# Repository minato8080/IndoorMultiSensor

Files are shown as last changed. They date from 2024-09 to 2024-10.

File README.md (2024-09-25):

## 概要
温度、湿度、気圧、二酸化炭素濃度、時間を毎秒k更新して表示する室内用汎用モニタです。
秋月電子の16×2行のLCDモジュールが安かったのでデュアルディスプレイにしました。

BME280・MHZ19Cモジュールのライブラリについてはこちらお借りしました。
https://github.com/shapoco/pico-env-mon

## 電子部品
|項目|型番|購入先|
|:--|:--|:--|
|マイコン|Raspberry Pi Pico|https://akizukidenshi.com/catalog/g/g116132/|
|LCD|ACM1602K-NLW-BBW *2|https://akizukidenshi.com/catalog/g/g110185/|
|温湿度・気圧センサ|AE-BME280|https://akizukidenshi.com/catalog/g/g109421/|
|CO2 センサ|MH-Z19C|https://akizukidenshi.com/catalog/g/g116142/|
|タクトスイッチ||https://akizukidenshi.com/catalog/g/g103647/|
|RTC|AE-RX8900|https://akizukidenshi.com/catalog/g/g113009/|
|電気二重層コンデンサー|1.5F5.5V|https://akizukidenshi.com/catalog/g/g104300/|
|整流用ダイオード|1000V1A|https://akizukidenshi.com/catalog/g/g100934/|
|抵抗|2.2kΩ *2|手持ち|
||560kΩ *2|手持ち|
||200kΩ|手持ち|
|ピンヘッダ||手持ち|
|ユニバーサル基板|2.54mmピッチ 7*9cm|https://www.amazon.co.jp/gp/product/B0CX1P8M42/|
|配線|UEW|https://akizukidenshi.com/catalog/g/g109583/|
||耐熱電子ワイヤ|https://akizukidenshi.com/catalog/g/g110672|
|USB電源|5V|手持ち|
|microUSBケーブル||手持ち|

## 配線図
ユニバーサル基盤を二層にして、LCDデュアルディスプレイを１層目、その他を2層目にしました。
MHZ19Cが大きな電流を吸い込むので電源付近に220µFのコンデンサを配置しています。
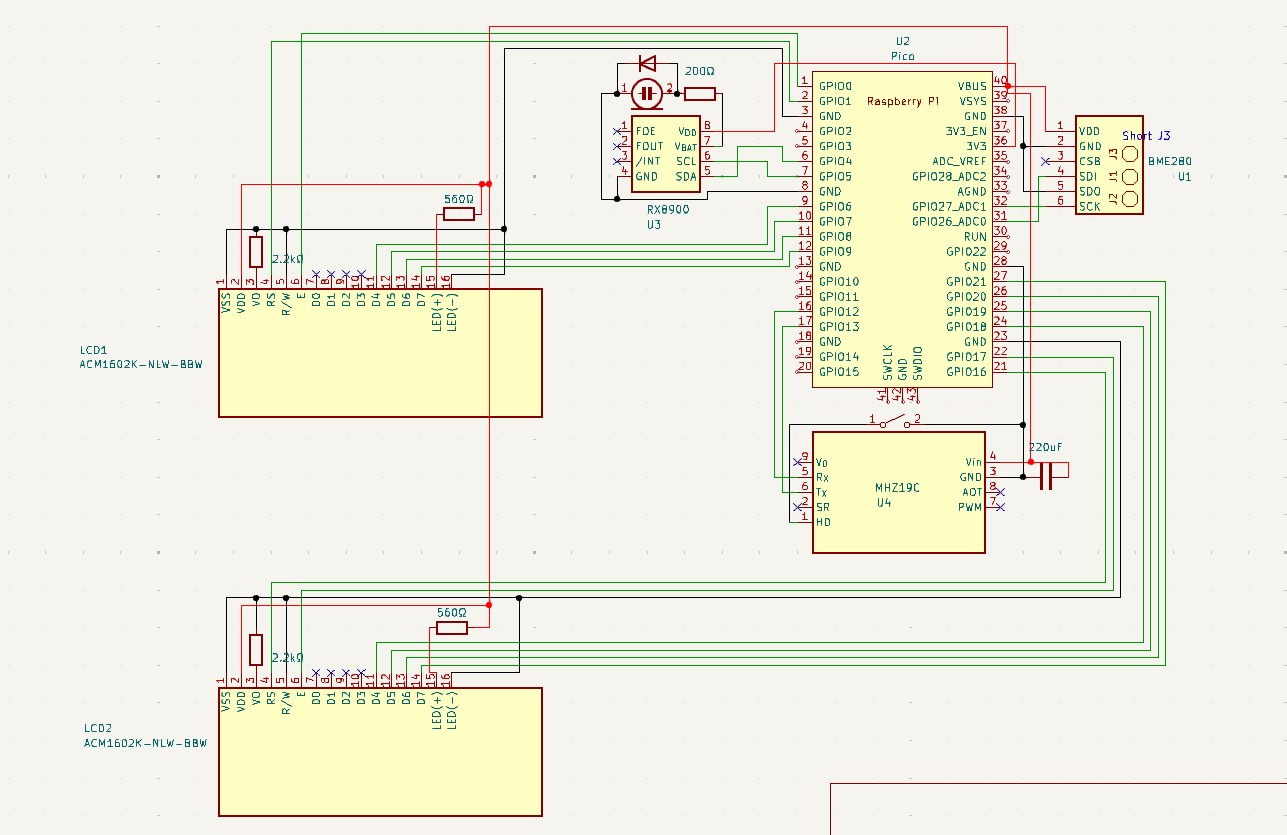
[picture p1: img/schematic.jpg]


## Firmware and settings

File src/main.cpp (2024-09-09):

#include <Arduino.h>
#include <LiquidCrystal.h>
#include <RX8900RTC.h>
#include <Wire.h>

#include "../lib/bme280.hpp"
#include "../lib/mhz19c.hpp"
#include "char_utils.hpp"
#include "time_utils.hpp"

// RTCモジュール
RX8900RTC RTC;
// LCDディスプレイ
LiquidCrystal lcd0(1, 0, 6, 7, 8, 9);
LiquidCrystal lcd1(16, 17, 18, 19, 20, 21);
// CO2センサ
MHZ19C mhz19c(uart0, 12, 13);
// 温湿度気圧センサ
BME280 bme280;

// 温度は湿度・気圧の補正用であり気温よりやや高いため適当に補正する
// 補正値の適正値はセンサの使用条件により異なる
static const float TEMPERATURE_OFFSET = -1.5f;

void serialCO2(LiquidCrystal lcd, MHZ19C mhz19c);
void serialEnvironment(LiquidCrystal lcd, BME280 bme280);

void setup() {
    // picoの場合setup内で再度begin
    Wire.begin();
    Wire1.begin();

    // LCDディスプレイ初期化
    lcd0.begin(16, 2);
    lcd1.begin(16, 2);
    // CO2センサ初期化
    mhz19c.init();
    // 温湿度気圧センサ初期化
    bme280.init();
    // RTCモジュール初期化
    RTC.init();

    // RTCの時刻とコンパイル時刻の新しい方をセット
    time_t time_now = RTC.get();
    time_t compiletime = compileTime();
    if (time_now < compiletime)
        RTC.set(compiletime);

    // テスト用
    Serial.begin(9600);
}

void loop() {
    serialTime(lcd1, RTC.read());
    serialCO2(lcd0, mhz19c);
    serialEnvironment(lcd0, bme280);
    delay(1000);
}

/** CO2を測定し、秋月I2C液晶ディスプレイに表示
 * \param[in] lcd LiquidCrystalインスタンス
 * \param[in] mhz19c MHZ19Cインスタンス
 */
void serialCO2(LiquidCrystal lcd, MHZ19C mhz19c) {
    // 文字変換用のバッファ
    char buffer[50];

    // CO2数値を読み取る
    int co2;
    mhz19c.measure(&co2);

    // LCDに出力
    lcd.setCursor(9, 1);
    lcd.print(padInt(co2, 4, ' ', buffer));
    lcd.setCursor(13, 1);
    lcd.print("ppm");
}

/** 温湿度気圧を測定し、秋月I2C液晶ディスプレイに表示
 * \param[in] lcd LiquidCrystalインスタンス
 * \param[in] bme280 BME280インスタンス
 */
void serialEnvironment(LiquidCrystal lcd, BME280 bme280) {
    // 文字変換用のバッファ
    char buffer[50];
    // 温度、気圧、湿度を読み取る
    float temperature, pressure, humidity;
    bme280.read_env(&temperature, &humidity, &pressure);
    temperature += TEMPERATURE_OFFSET;

    // LCDに出力
    // 温度
    lcd.setCursor(0, 0);
    lcd.print(padFloat(temperature, 2, 1, ' ', buffer));
    lcd.setCursor(4, 0);
    lcd.print(char(223)); // '゜'記号
    lcd.setCursor(5, 0);
    lcd.print('C');
    // 気圧
    lcd.setCursor(7, 0);
    lcd.print(padFloat(pressure, 4, 1, ' ', buffer));
    lcd.setCursor(13, 0);
    lcd.print("hPa");
    // 湿度
    lcd.setCursor(0, 1);
    lcd.print(padFloat(humidity, 2, 1, ' ', buffer));
    lcd.setCursor(4, 1);
    lcd.print('%');
}

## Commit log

2024-09-15 Add kiCad drawing.
    [IndoorMultiSensor.kicad_pcb, IndoorMultiSensor.kicad_sch]
2024-09-15 CAD schematics completed.
    [IndoorMultiSensor.kicad_sch]
2024-09-15 Modified CAD appearance.
    [IndoorMultiSensor.kicad_sch]
2024-10-05 fixed footprint symbols
    [IndoorMultiSensor.kicad_sch]
